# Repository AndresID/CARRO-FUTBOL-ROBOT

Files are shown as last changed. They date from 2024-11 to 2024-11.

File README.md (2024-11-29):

# CARRO FUTBOL-ROBOT ⚽

Carro a control remoto con mecanismo de pateo para impactar una pelota de ping pong, utilizado en competencias de **FUTBOL-ROBOT**.

Para la competencia fue necesaria la implementación de 2 carros rc.

carros en cancha

## Componentes del proyecto.
-2x Arduino UNO.

-2x Shield Joystick para Arduino UNO.

-2x Micro Servo SG-90.

-2x Arduino NANO.

-2x LM1117T.

-4x Capacitores electroliticos de 10uF.

-2x Modulo L298n.

-4 Motores N20-30 6V 300rpm.

-4x nRF24L01+.

## Arduino NANO
Arduino NANO
## nRF24L01
El nRF24L01+ (de Nordic Semiconductor) es un transceptor RF de 2 Mbps de potencia ultrabaja (ULP) altamente integrado para la banda ISM (industrial, científica y médica) de 2,4 GHz.

nrf24l01
nrf24l01+

#### Características:

-Fuente de alimentación: 1,9 ~ 3,6 V.

-Alcance de ~520 m a velocidad de datos de 2 Mbit

-Reconocimiento automático

-Retransmisión automática

-Multireceptor - 6 conductos de datos

-FIFO TX y RX separados de 32 bytes

-Canal seleccionable por software: 2400 MHz a 2525 MHz (125 canales seleccionables)

-Número mínimo de componentes externos

-Pines desglosados: VCC, CE, CSN, SCK, MOSI, MISO, IRQ, GND

nRF24L01+ es un transceptor de banda estrecha (~2 MHz), pero eso funciona a nuestro favor ya que BLE también es de banda estrecha por diseño (~2 MHz).

## Esquemas
- Importante utilizar un reductor de voltaje como por ejemplo el reductor de voltaje lineal LM1117T.

LM1117T

Esquematico nano_nrf24l01

### Servo SG-90
MICROSERVO-SG90
### Características
• Weight: 9 g

• Dimension: 22.2 x 11.8 x 31 mm approx.

• Stall torque: 1.8 kgf·cm

• Operating speed: 0.1 s/60 degree

• Operating voltage: 4.8 V (~5V)

• Dead band width: 10 μs

• Temperature range: 0 ºC – 55 ºC 

## Arduino UNO
Arduino UNO

## Shield Joystick Arduino UNO
- Este modulo es comunmente utilizado en proyectos de radio control por su facilidad de implementacion ya que es plug and play.

shield joystick arduino uno

## Modulo L298n
L298n
### Características

- Input Voltage: 3.2V~40Vdc.

- Driver: L298N Dual H Bridge DC Motor Driver

- Power Supply: DC 5 V - 35 V

- Peak current: 2 Amp

- Operating current range: 0 ~ 36mA

- Control signal input voltage range :

- Low: -0.3V ≤ Vin ≤ 1.5V.

- High: 2.3V ≤ Vin ≤ Vss.

- Enable signal input voltage range :

  - Low: -0.3 ≤ Vin ≤ 1.5V (control signal is invalid).

   - High: 2.3V ≤ Vin ≤ Vss (control signal active).

- Maximum power consumption: 20W (when the temperature T = 75 ℃).

- Storage temperature: -25 ℃ ~ +130 ℃.

- On-board +5V regulated Output supply (supply to controller board i.e. Arduino).

- Size: 3.4cm x 4.3cm x 2.7cm 

## Motores motores N20-30
motor n20
### Características
- Material: Metal

- Modelo: N20

- Longitud Total: 36mm

- Tamaño de motor: 12mm(diámetro)*26mm(altura)

- Tamaño de eje: 3mm(diámetro)*10mm(longitud)

- Rango de Voltaje: 3-9VDC

- Voltaje Nominal: 6VDC

- Velocidad sin Carga: 300rpm

- Corriente sin Carga: 30mA

- Corriente a Máxima Eficiencia: 40mA

- Torque de Paro (Stall Torque): 1.6Kg/cm

- Corriente de Paro (Stall Current): 0.4A

## Implementación
### Diseño
#### Carro
medidas_carro
medidas_chute
DISEÑO CARRO

#### Control
control

### Baquelita
Baquielita carro

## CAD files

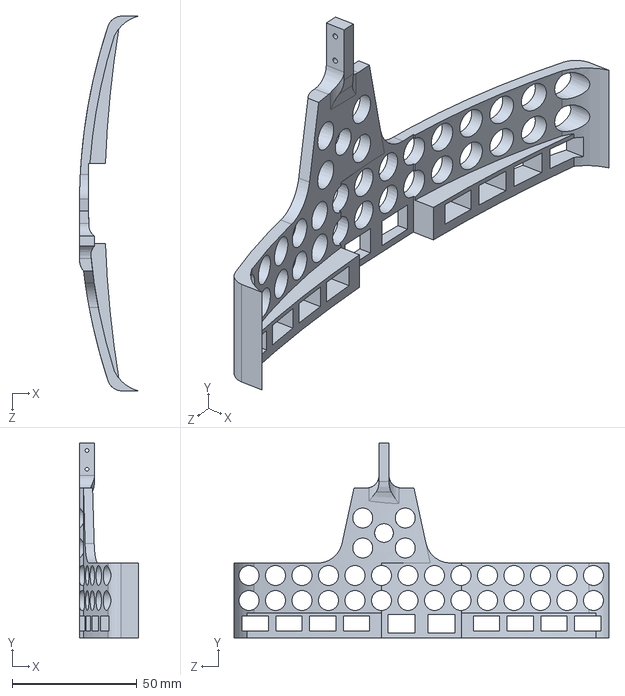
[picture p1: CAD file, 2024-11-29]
DISEÑO/CHUTE PRO.SLDPRT
23.6 x 78.0 x 150.0 mm

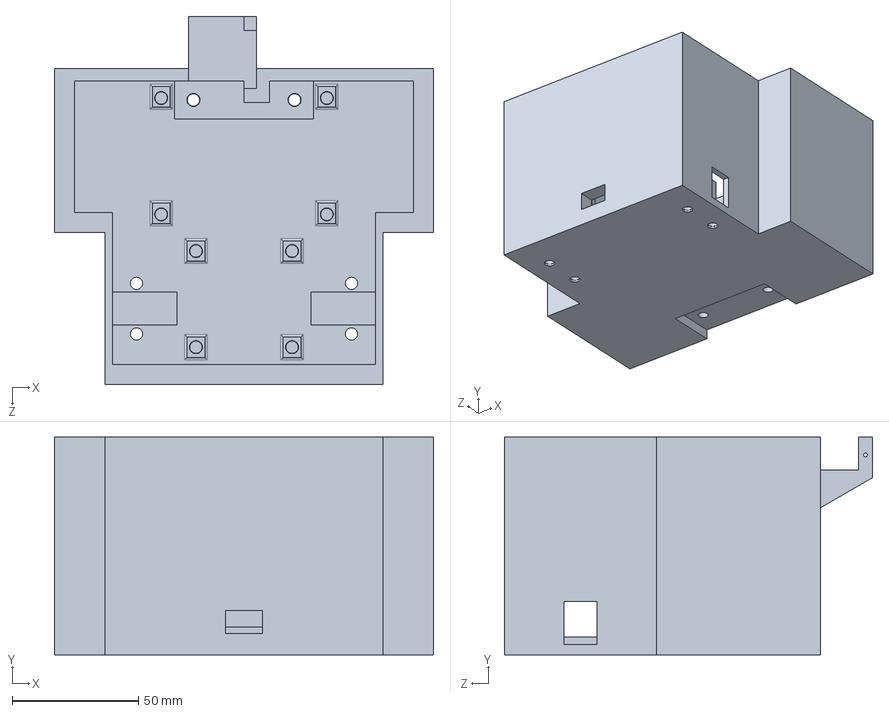
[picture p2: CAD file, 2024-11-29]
DISEÑO/BASE PRO.SLDPRT
150.0 x 86.0 x 145.5 mm

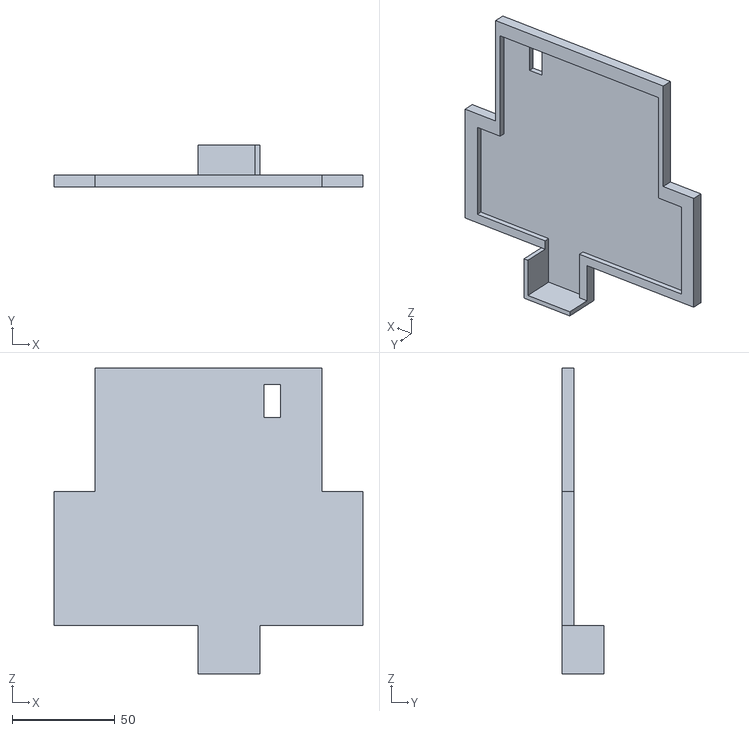
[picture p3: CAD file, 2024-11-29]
STL/TAPA BASE BUENA.STL
150.0 x 20.5 x 148.5

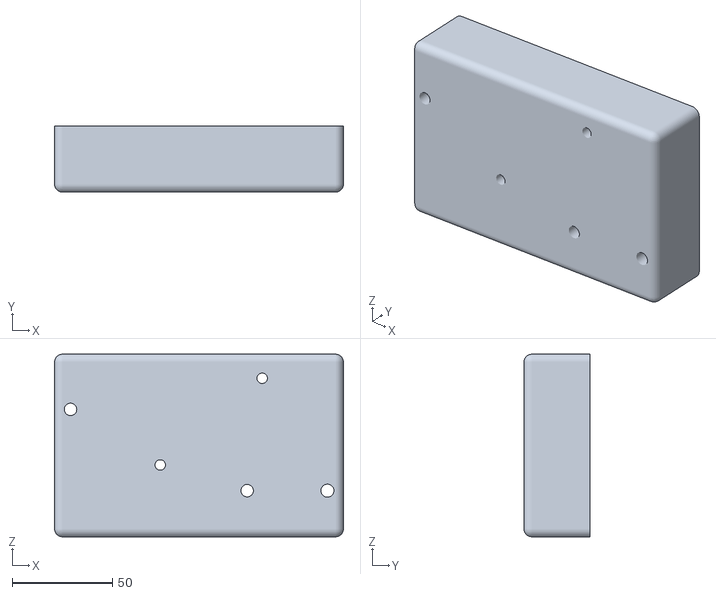
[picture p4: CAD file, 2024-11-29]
STL/CONTROL.STL
144.0 x 33.0 x 91.0

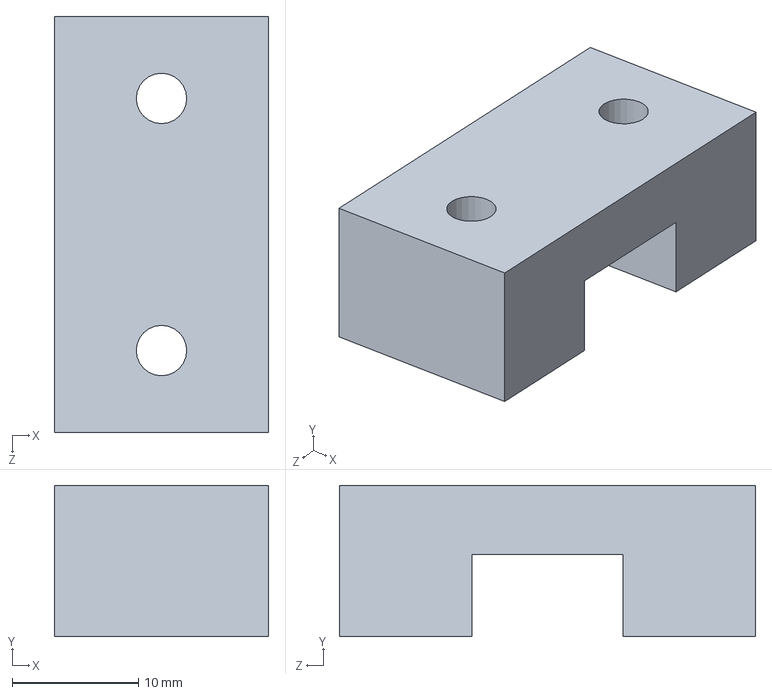
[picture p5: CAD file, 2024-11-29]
DISEÑO/SOPORTE DE MOTOR N20.SLDPRT
17.0 x 12.0 x 33.0 mm

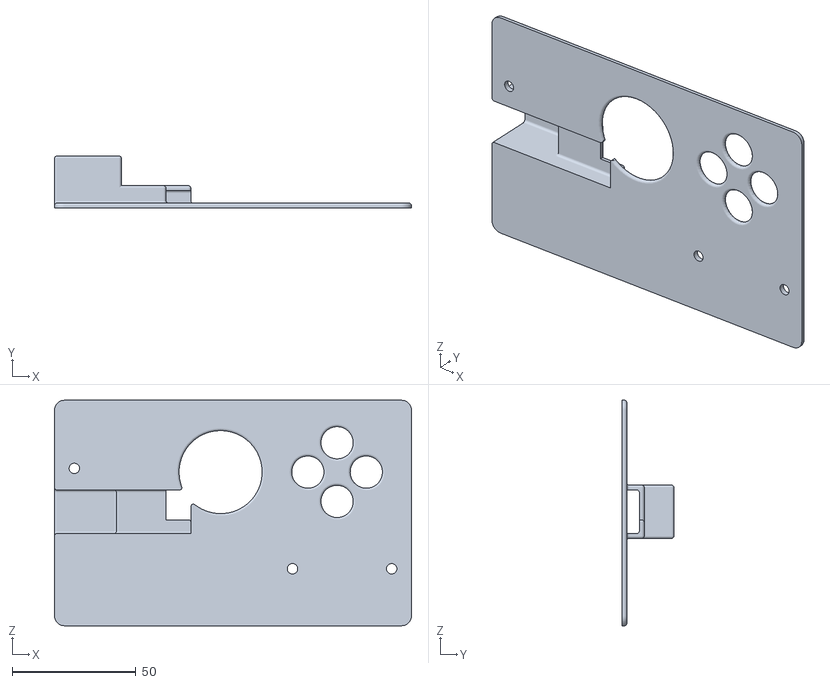
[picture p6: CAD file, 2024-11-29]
STL/TAPA CONTROL.STL
144.0 x 21.0 x 91.0

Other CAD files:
STL/CHUTE PRO.STL
DISEÑO/TAPA BASE BUENA.SLDPRT
STL/SOPORTE DE MOTOR N20.STL
DISEÑO/CONTROL.SLDPRT
DISEÑO/TAPA CONTROL.SLDPRT
STL/BASE PRO.STL

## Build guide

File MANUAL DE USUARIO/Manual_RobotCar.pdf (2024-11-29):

Manual RobotCar

Realizado por:

Andres Redondo

Dariana Torrecilla

Correos de contacto:

andresfelipe.redondo@ustabuca.edu.co

darianaandrea.torrecilla@ustabuca.edu.co

1. Encendido.
Se va a alimentar con 3 baterías 18650, ubicadas dentro del carros, a las que se puede acceder retirando la tapa que se encuentra en la parte superior del robot, al retirar los siguientes tornillos:

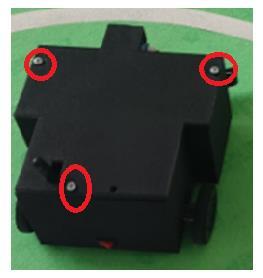
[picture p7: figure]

Luego de colocar las baterías y asegurar la tapa con los tornillos, se procede a encender el carro mediante el interruptor ubicado en la parte trasera inferior del carro:

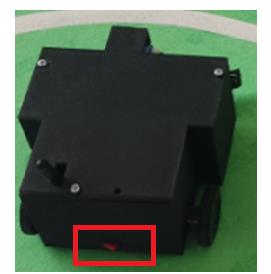
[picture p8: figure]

Ahora con el carro encendido se procede a encender el control con el interruptor ubicado en la cara frontal del mando.

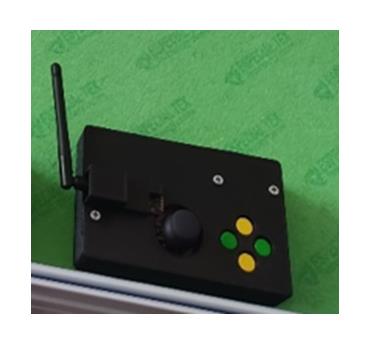
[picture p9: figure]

Si el control no funciona de forma correcta, asegúrate de que las baterías estén cargadas, para verificar esto, debes retirar los siguientes tornillos:

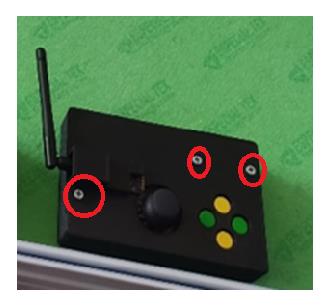
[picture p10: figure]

2. Funcionamiento de mando
Para el control del carro se tienen establecidos los siguientes comandos:
Cada botón tiene una función específica, el botón A es para avanzar, el botón C para retroceder, el botón B girar a la derecha, el botón D girar a la izquierda, y el pulsador del Joystick es par accionar el servo, hay 3 modos de operación (0, 1, 2) se seleccionan al presionar botones múltiples veces.
- Modo 0: Movimiento básico y servo activado.
- Modo 1: Un motor apagado en ciertos movimientos.
- Modo 2: Velocidad reducida en un motor.

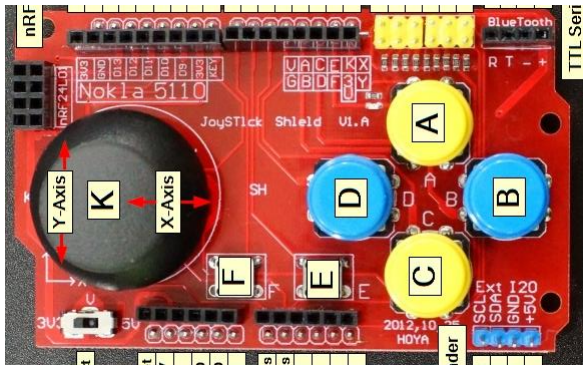
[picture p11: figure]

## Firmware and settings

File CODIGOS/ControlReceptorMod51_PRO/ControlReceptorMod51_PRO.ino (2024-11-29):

#include <SPI.h>
#include <nRF24L01.h>
#include <RF24.h>
#include <Servo.h>  

// Pines botones

// Pines del Puente H

// Motor 1
#define IN1 8  // Motor 1 adelante
#define IN2 7  // Motor 1 atrás  
#define ENA 6  // PWM Motor 1

// Motor 2
#define IN3 4  // Motor 2 adelante
#define IN4 2  // Motor 2 atrás
#define ENB 5  // PWM Motor 2

// Pin del Servo
//#define ServoPIN 3  // PWM para el servo

// Configuración NRF24L01
RF24 radio(9, 10);  // CE, CSN
const byte direccion[6] = "00001";


struct DatosControl {
  
  bool leftx; // 
  bool rightx;
  bool downy;
  bool upy; 
  bool accservo;
  int program = 0;
};

DatosControl datosControl;
Servo miServo;  // Crear objeto servo

void setup() {
  
  Serial.begin(9600);
  
  // Configuración de los pines del motor
  pinMode(IN1, OUTPUT);
  pinMode(IN2, OUTPUT);
  pinMode(ENA, OUTPUT);

  pinMode(IN3, OUTPUT);
  pinMode(IN4, OUTPUT);
  pinMode(ENB, OUTPUT);

  // Configuración del servo
  miServo.attach(3);  // Conectar el servo al pin definido
  miServo.write(0);  // Iniciar el servo en la posición neutral (90 grados)

  // Inicializar el módulo NRF24L01
  radio.begin();
  if (!radio.begin()) {
    Serial.println("No se pudo Iniciar el módulo RF");
    while (1);
  }
  radio.setChannel(51);
  radio.openReadingPipe(0, direccion);
  radio.startListening();  // Comenzar a escuchar las señales del emisor
}

void loop() {
  if (radio.available()) {
    radio.read(&datosControl, sizeof(datosControl));
    
    /////////////////////////////////////////////////////////////////////////
    // PROGRAMA 0 GIRA EN SU PROPIO EJE
    if(datosControl.program == 0){

      if ( datosControl.upy == true){ //Adelante
        digitalWrite(IN1, HIGH);
        digitalWrite(IN2, LOW);
        digitalWrite(IN3, HIGH);
        digitalWrite(IN4, LOW);
        analogWrite(ENA, 255);
        analogWrite(ENB, 255);

      } 

      else if (datosControl.downy == true) { //Atrás
        digitalWrite(IN1, LOW);
        digitalWrite(IN2, HIGH);
        digitalWrite(IN3, LOW);
        digitalWrite(IN4, HIGH);
        analogWrite(ENA, 255);
        analogWrite(ENB, 255);

      } 

      else { //Stop
        digitalWrite(IN1, LOW);
        digitalWrite(IN2, LOW);
        digitalWrite(IN3, LOW);
        digitalWrite(IN4, LOW);
      
      }

      if (datosControl.rightx == true){ //Derecha
        digitalWrite(IN1, LOW);
        digitalWrite(IN2, HIGH);
        digitalWrite(IN3, HIGH);
        digitalWrite(IN4, LOW);
        analogWrite(ENA, 255);
        analogWrite(ENB, 255);

      } 

      else if (datosControl.leftx == true) { //Izquierda
        digitalWrite(IN1, HIGH);
        digitalWrite(IN2, LOW);
        digitalWrite(IN3, LOW);
        digitalWrite(IN4, HIGH);
        analogWrite(ENA, 255);
        analogWrite(ENB, 255);

      } 
        
      if (datosControl.accservo == true) {
        miServo.write(30);  // Mueve el servo a 90 grados cuando se presiona el botón
        delay(100);

      } 
      else {
        miServo.write(0);  // Mueve el servo a la posición neutral (0 grados)
      } 
    // Control del servo usando el botón del joystick
    }

    /////////////////////////////////////////////////////////////////////////
    // PROGRAMA 1 APAGA UN MOTOR
    if(datosControl.program == 1){

      if ( datosControl.rightx == true){ //Adelante
        digitalWrite(IN1, LOW);
        digitalWrite(IN2, HIGH);
        digitalWrite(IN3, HIGH);
        digitalWrite(IN4, LOW);
        analogWrite(ENA, 255);
        analogWrite(ENB, 255);

      } 

      else if (datosControl.leftx == true) { //Atrás
        digitalWrite(IN1, HIGH);
        digitalWrite(IN2, LOW);
        digitalWrite(IN3, LOW);
        digitalWrite(IN4, HIGH);
        analogWrite(ENA, 255);
        analogWrite(ENB, 255);

      } 

      else { //Stop
        digitalWrite(IN1, LOW);
        digitalWrite(IN2, LOW);
        digitalWrite(IN3, LOW);
        digitalWrite(IN4, LOW);
      
      }

      if (datosControl.upy == true){ //Derecha
        digitalWrite(IN1, HIGH);
        digitalWrite(IN2, LOW);
        digitalWrite(IN3, HIGH);
        digitalWrite(IN4, LOW);
        analogWrite(ENA, 0);
        analogWrite(ENB, 255);

      } 

      else if (datosControl.downy == true) { //Izquierda
        digitalWrite(IN1, LOW);
        digitalWrite(IN2, HIGH);
        digitalWrite(IN3, HIGH);
        digitalWrite(IN4, LOW);
        analogWrite(ENA, 255);
        analogWrite(ENB, 0);

      } 
        
      if (datosControl.accservo == true) {
        miServo.write(30);  // Mueve el servo a 90 grados cuando se presiona el botón
        delay(100);

      } 
      else {
        miServo.write(0);  // Mueve el servo a la posición neutral (0 grados)
      } 
    // Control del servo usando el botón del joystick
    }
    
    /////////////////////////////////////////////////////////////////////////
    // PROGRAMA 2 APAGA UN MOTOR
    if(datosControl.program == 2){

      if ( datosControl.rightx == true){ //Adelante
        digitalWrite(IN1, LOW);
        digitalWrite(IN2, HIGH);
        digitalWrite(IN3, HIGH);
        digitalWrite(IN4, LOW);
        analogWrite(ENA, 255);
        analogWrite(ENB, 255);

      } 

      else if (datosControl.leftx == true) { //Atrás
        digitalWrite(IN1, HIGH);
        digitalWrite(IN2, LOW);
        digitalWrite(IN3, LOW);
        digitalWrite(IN4, HIGH);
        analogWrite(ENA, 255);
        analogWrite(ENB, 255);

      } 

      else { //Stop
        digitalWrite(IN1, LOW);
        digitalWrite(IN2, LOW);
        digitalWrite(IN3, LOW);
        digitalWrite(IN4, LOW);
      
      }

      if (datosControl.upy == true){ //Derecha
        digitalWrite(IN1, LOW);
        digitalWrite(IN2, HIGH);
        digitalWrite(IN3, HIGH);
        digitalWrite(IN4, LOW);
        analogWrite(ENA, 45);
        analogWrite(ENB, 255);

      } 

      else if (datosControl.downy == true) { //Izquierda
        digitalWrite(IN1, LOW);
        digitalWrite(IN2, HIGH);
        digitalWrite(IN3, HIGH);
        digitalWrite(IN4, LOW);
        analogWrite(ENA, 255);
        analogWrite(ENB, 45);

      } 
        
      if (datosControl.accservo == true) {
        miServo.write(30);  // Mueve el servo a 90 grados cuando se presiona el botón
        delay(100);

      } 
      else {
        miServo.write(0);  // Mueve el servo a la posición neutral (0 grados)
      } 
      // Control del servo usando el botón del joystick
    }
        
  }
}

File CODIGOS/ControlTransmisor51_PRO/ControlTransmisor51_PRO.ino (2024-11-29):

#include <SPI.h>
#include <nRF24L01.h>
#include <RF24.h>
#include <Servo.h>

// Pines del joystick
#define up     3 // Botón adelante
#define right  2 // Botón derecha
#define down   5 // Botón abajo
#define left   4 // Botón izquierda
#define buttonservo 8

int buttonPressCount1 = 0;
int buttonPressCount2 = 0;
int buttonPressCount3 = 0;

unsigned long lastPressTime1 = 0;
unsigned long lastPressTime2 = 0;
unsigned long lastPressTime3 = 0;
const unsigned long resetDelay = 500; 

bool buttonPressed1 = false;
bool buttonPressed2 = false;  
bool buttonPressed3 = false;   

const int buttonPin1 = 3;            // Pin donde está conectado el botón
const int buttonPin2 = 5;            // Pin donde está conectado el botón
const int buttonPin3 = 4;            // Pin donde está conectado el botón

// Configuración NRF24L01
RF24 radio(9, 10);  // CE, CSN
const byte direccion[6] = "00001";  // Dirección para el canal de comunicación

// Estructura de los datos que se enviarán
struct DatosControl {
  bool leftx; 
  bool rightx;
  bool downy;
  bool upy; 
  bool accservo;
  int program = 0;
};
DatosControl datosControl;

void setup() {
  Serial.begin(9600);
  pinMode(up, INPUT_PULLUP);
  pinMode(right, INPUT_PULLUP);
  pinMode(down, INPUT_PULLUP);
  pinMode(left, INPUT_PULLUP);
  pinMode(buttonservo, INPUT);

  radio.begin();
  if (!radio.begin()) {
    while (1); // Mantener en bucle si el módulo no se inicializa
  }

  // Configurar la dirección de escritura para el NRF24L01
  radio.setChannel(51);
  radio.openWritingPipe(direccion);
  radio.setPALevel(RF24_PA_MIN); // Establecer el nivel de potencia de la señal
  radio.stopListening();
}

void loop() {
  int buttonState1 = digitalRead(buttonPin1); // Lee el estado del botón
  int buttonState2 = digitalRead(buttonPin2); // Lee el estado del botón
  int buttonState3 = digitalRead(buttonPin3); // Lee el estado del botón

  datosControl.upy = !digitalRead(up);
  datosControl.rightx = !digitalRead(right);
  datosControl.downy = !digitalRead(down);
  datosControl.leftx = !digitalRead(left);
  datosControl.accservo = !digitalRead(buttonservo);

  /////////////////////////////////////////////////////////////////////////////////////////////

  // Manejando el primer botón
  if (buttonState1 == HIGH && !buttonPressed1) {
    buttonPressCount1++;
    lastPressTime1 = millis(); // Actualiza el tiempo de la última pulsación
    buttonPressed1 = true;      // Marca que el botón está presionado
  } 
  else if (buttonState1 == LOW) {
    buttonPressed1 = false;     // Marca que el botón está suelto
  }
  
  /////////////////////////////////////////////////////////////////////////////////////////////

  // Manejando el segundo botón
  if (buttonState2 == HIGH && !buttonPressed2) {
    buttonPressCount2++;
    lastPressTime2 = millis(); // Actualiza el tiempo de la última pulsación
    buttonPressed2 = true;      // Marca que el botón está presionado
  } 
  else if (buttonState2 == LOW) {
    buttonPressed2 = false;     // Marca que el botón está suelto
  }
  
  /////////////////////////////////////////////////////////////////////////////////////////////

  // Manejando el tercer botón
  if (buttonState3 == HIGH && !buttonPressed3) {
    buttonPressCount3++;
    lastPressTime3 = millis(); // Actualiza el tiempo de la última pulsación
    buttonPressed3 = true;      // Marca que el botón está presionado
  } 
  else if (buttonState3 == LOW) {
    buttonPressed3 = false;     // Marca que el botón está suelto
  }

  // Verificación de tiempo de reseteo para el primer botón
  if (millis() - lastPressTime1 >= resetDelay) {
    buttonPressCount1 = 0; // Resetea el contador
  }
  
  // Comprueba si se ha alcanzado el límite de pulsos para el primer botón
  if (buttonPressCount1 >= 3) {
    datosControl.program = 1;
    buttonPressCount1 = 0; // Resetea el contador
  }

  // Verificación de tiempo de reseteo para el segundo botón
  if (millis() - lastPressTime2 >= resetDelay) { // pin 2 arriba
    buttonPressCount2 = 0; // Resetea el contador
  }
  
  // Comprueba si se ha alcanzado el límite de pulsos para el segundo botón
  if (buttonPressCount2 >= 3) { // pin 3 derecha
    datosControl.program = 2;
    buttonPressCount2 = 0; // Resetea el contador
  }

  // Verificación de tiempo de reseteo para el tercer botón
  if (millis() - lastPressTime3 >= resetDelay) { 
    buttonPressCount3 = 0; // Resetea el contador
  }
  
  // Comprueba si se ha alcanzado el límite de pulsos para el tercer botón
  if (buttonPressCount3 >= 3) { // pin 4 abajo
    datosControl.program = 0;
    buttonPressCount3 = 0; // Resetea el contador
  }

  // Enviar los datos a través del módulo NRF24L01
  radio.write(&datosControl, sizeof(datosControl));

  Serial.println(datosControl.program);
  // Retardo para evitar sobrecarga de datos
  delay(50);
}

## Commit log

2024-11-29 Rename BASE PRO.SLDPRT to DISEÑO/BASE PRO.SLDPRT
    [BASE PRO.SLDPRT]
2024-11-29 Rename CHUTE PRO.SLDPRT to DISEÑO/CHUTE PRO.SLDPRT
    [CHUTE PRO.SLDPRT]
2024-11-29 Rename SOPORTE DE MOTOR N20.SLDPRT to DISEÑO/SOPORTE DE MOTOR N20.SLDPRT
    [SOPORTE DE MOTOR N20.SLDPRT]
2024-11-29 Rename TAPA BASE BUENA.SLDPRT to DISEÑO/TAPA BASE BUENA.SLDPRT
    [TAPA BASE BUENA.SLDPRT]
2024-11-29 Rename TAPA CONTROL.SLDPRT to DISEÑO/TAPA CONTROL.SLDPRT
    [TAPA CONTROL.SLDPRT]
